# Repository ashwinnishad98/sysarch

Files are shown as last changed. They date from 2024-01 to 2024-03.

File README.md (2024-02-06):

# Non-invasive Sleep Analysis Device

## Description
This device aims to provide a non-invasive way of tracking an individual's sleep quality. It will leverage a force sensor that is placed underneath a mattress to quantify time spent in Rapid Eye Movement (REM) and Non-Rapid Eye Movement (Non-REM) sleep. The user will be able to see their sleep quality once awake, through a stepper-motor controlled gauge needle that indicated sleep quality percentage, which ranges from 0-100%.
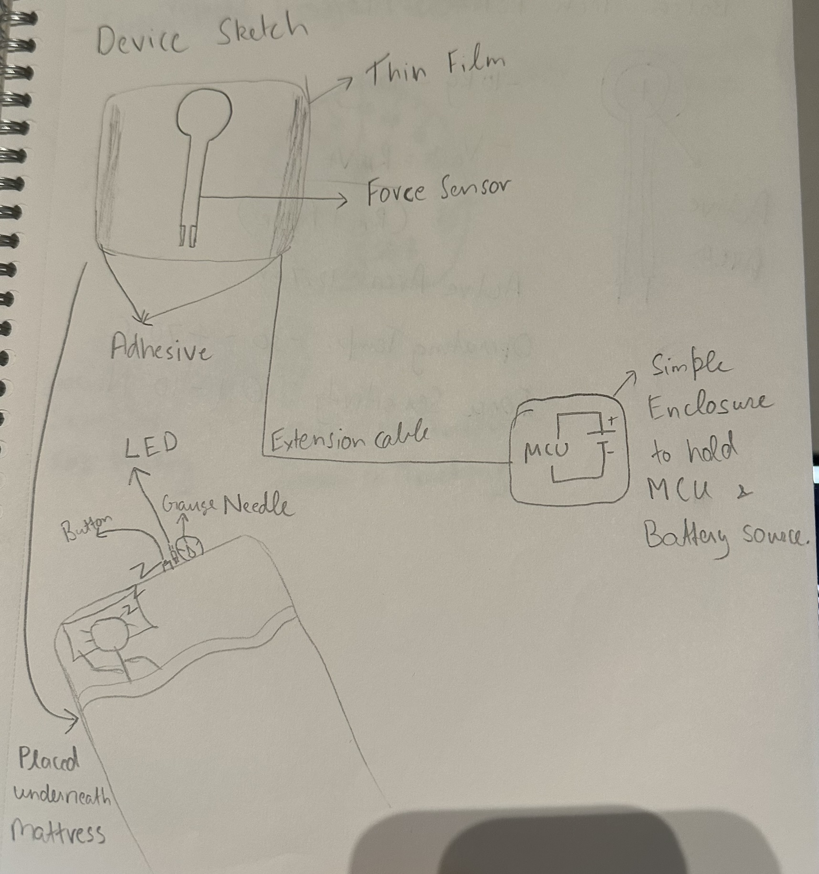
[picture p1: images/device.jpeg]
Device Sketch


## Power Consumption Spreadsheet
[URL](https://docs.google.com/spreadsheets/d/1Ds0gf-FW2-m5mJB0DvBmWuOtr-a-fM6qRe99MvLTX7Y/edit#gid=1000455818)

# Processor
## Seeed Xiao ESP32 S3
This microcontroller has both Wi-Fi and bluetooth capabilties, combined with a small form factor which is ideal for this device. It has 2 pins that can be used for supplying voltage, either 5V or 3.3V.

# Sensor
## Force Sensor: Bolsen Tech FSR402
This is a force sensor, that essentially converts pressure applied against the sensor into changes in resistance. This can be placed underneath the mattress to identify and track body movement over the sleep tracking period. It can be used within a range of 10KG-100KG.
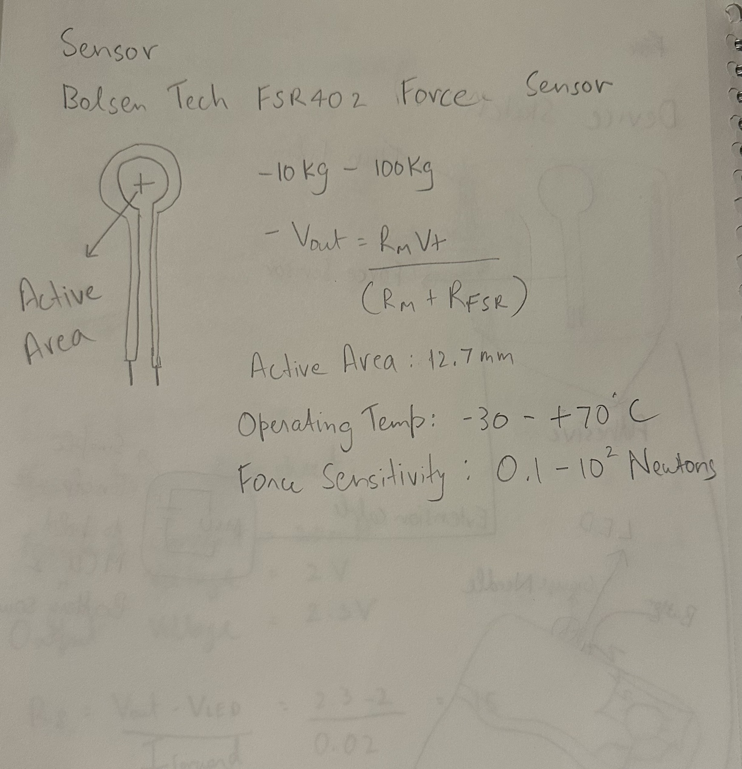
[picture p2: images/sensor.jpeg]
Sensor Sketch


# Displays
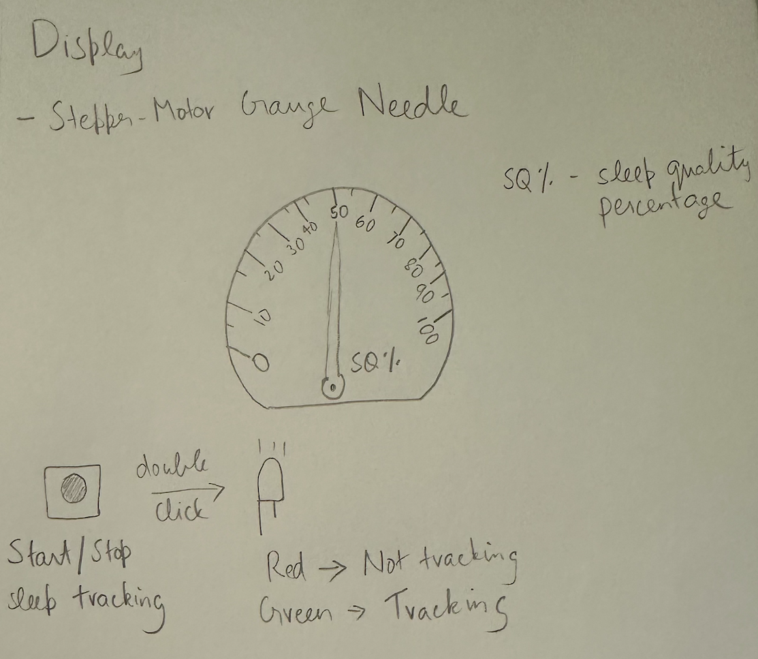
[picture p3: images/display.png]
Display Sketch

## Button
The button will be used by the user to start/stop the sleep tracking. Additionally, it will be programmed to where a double click shows if the device is currently tracking sleep through the LED output.

## LED
The LED will be used to indicate whether the device is currently tracking sleep and will be activated by the button. Upon double clicking the button, red will indicate that the device is not tracking and green will indicate vice-versa.

## Stepper-motor Needle Gauge
The needle gauge will display the measure of sleep quality in percentage. This output is triggered when the user clicks the button to stop the sleep tracking.

## System Architecture Diagram
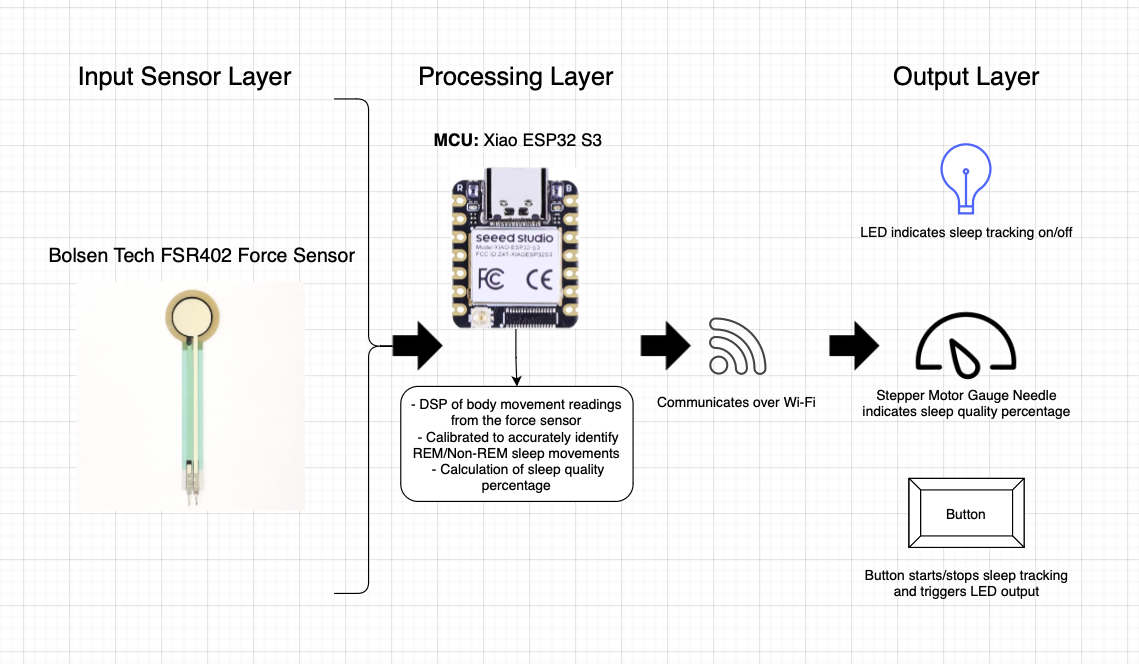
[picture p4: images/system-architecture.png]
System Architecture


## Functionality Diagram
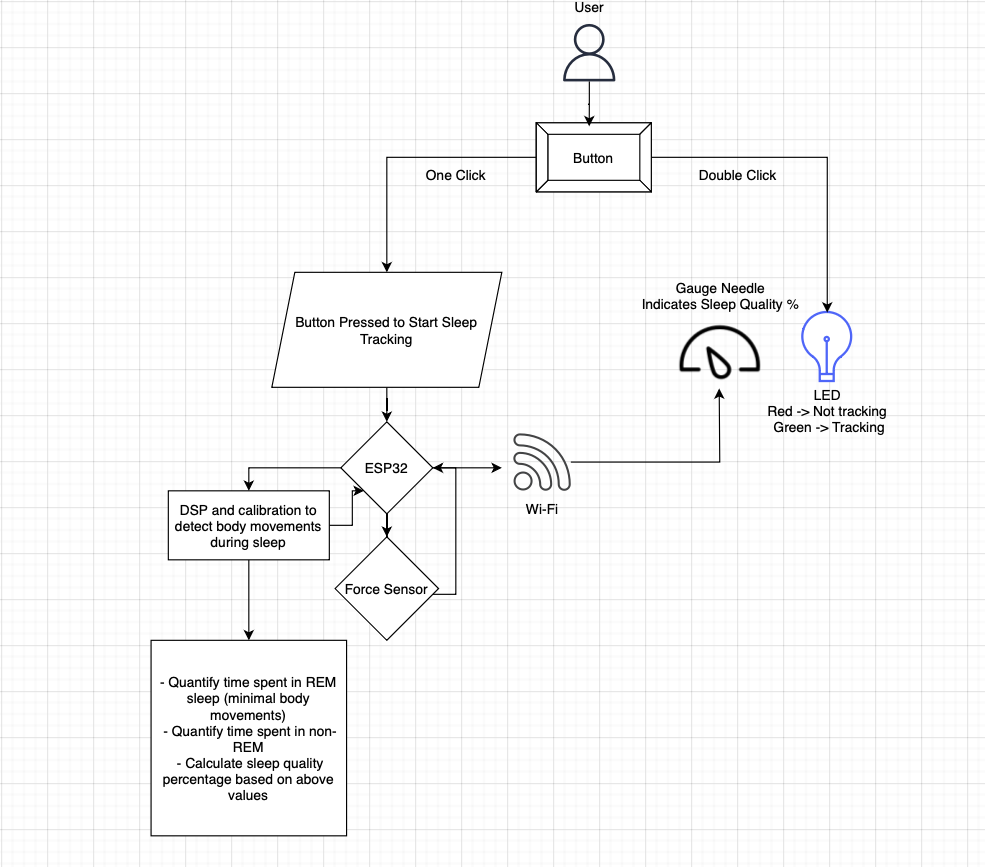
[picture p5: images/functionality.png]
Functionality


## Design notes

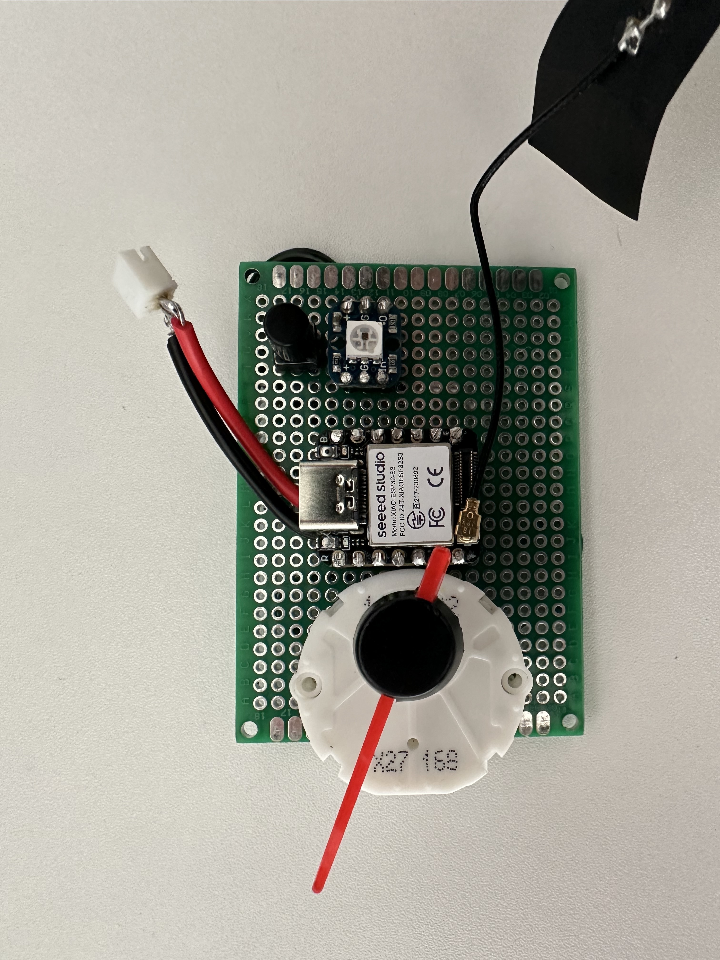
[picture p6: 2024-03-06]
images/displayPerf.jpg

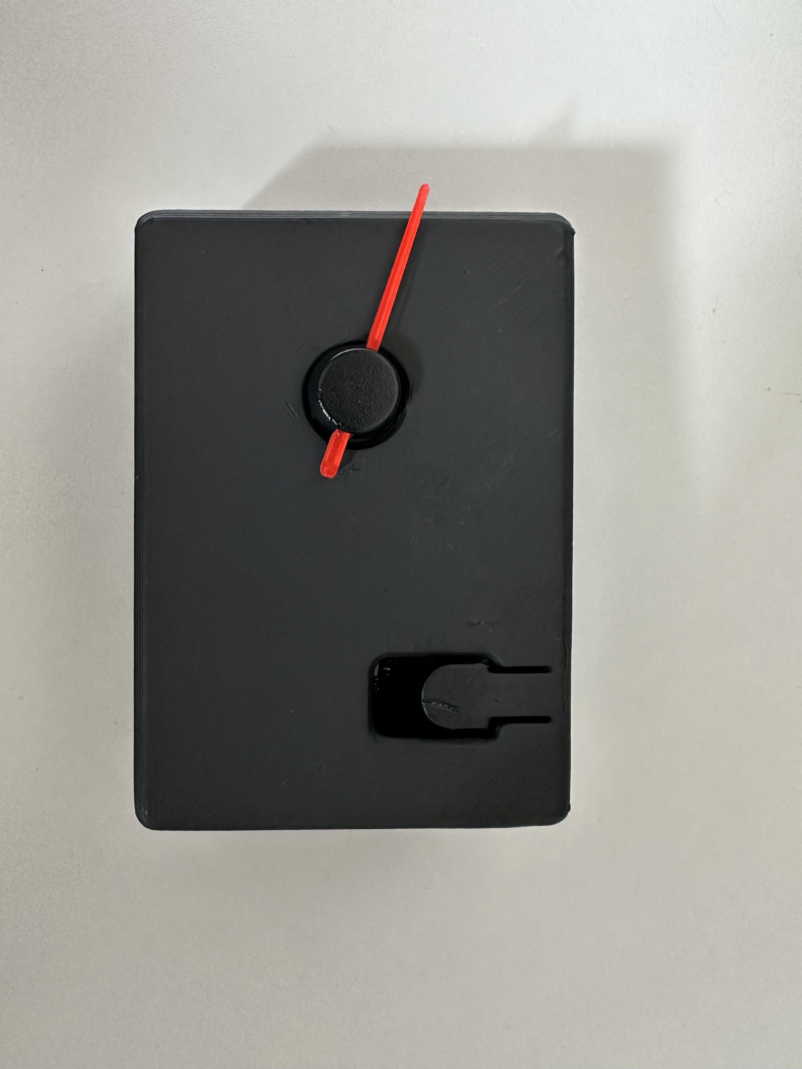
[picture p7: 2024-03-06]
images/display1.jpg

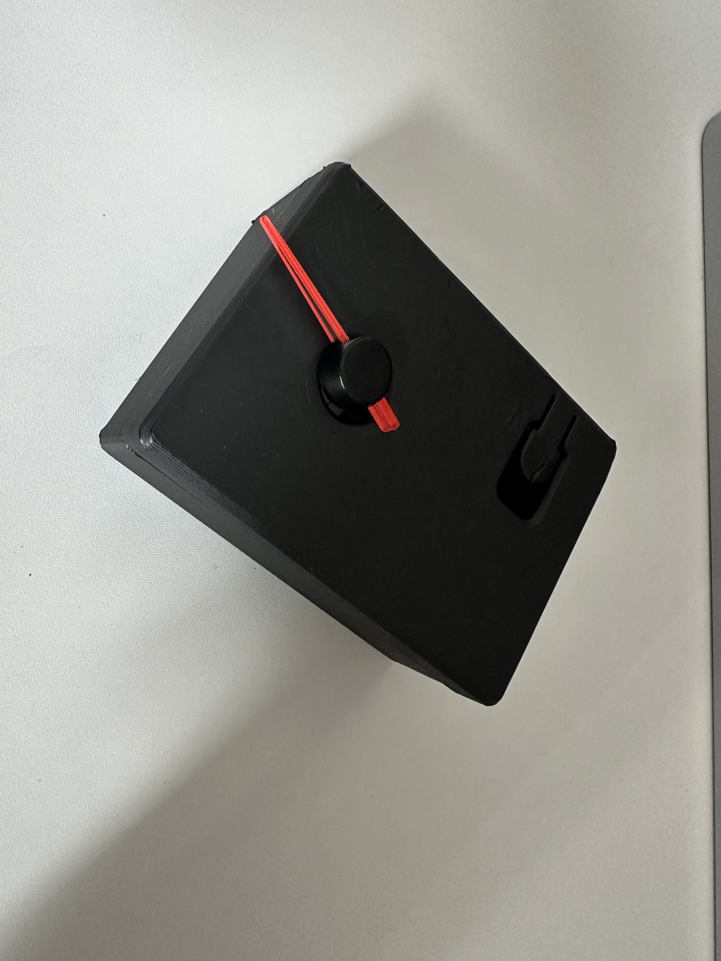
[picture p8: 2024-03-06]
images/display.jpg

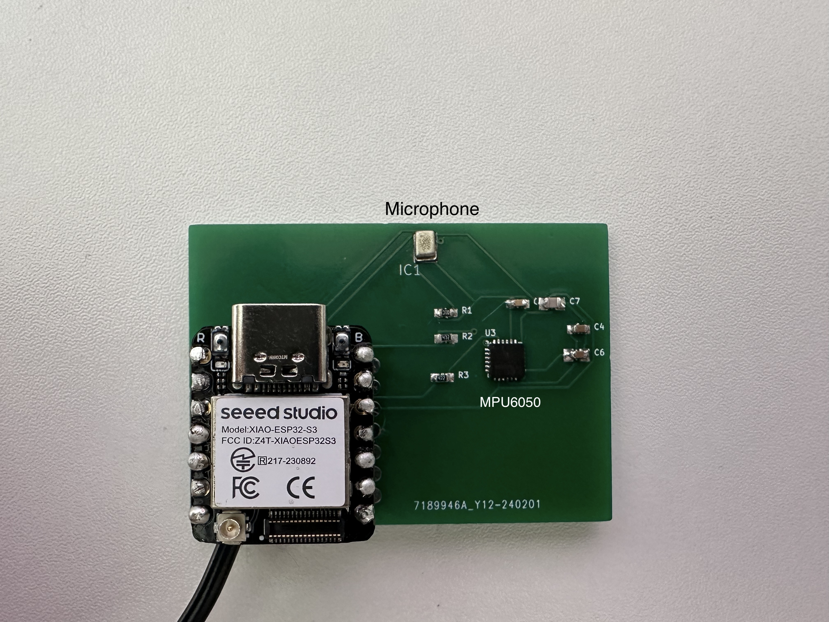
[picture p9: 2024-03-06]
images/pcb.jpg

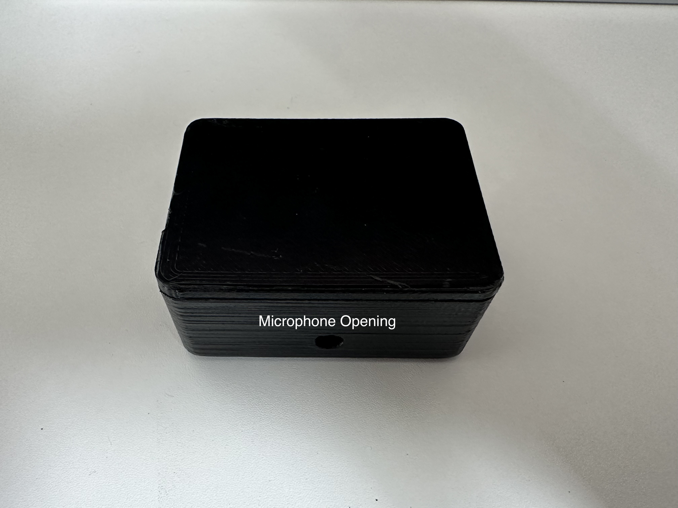
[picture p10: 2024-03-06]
images/sensing.jpg

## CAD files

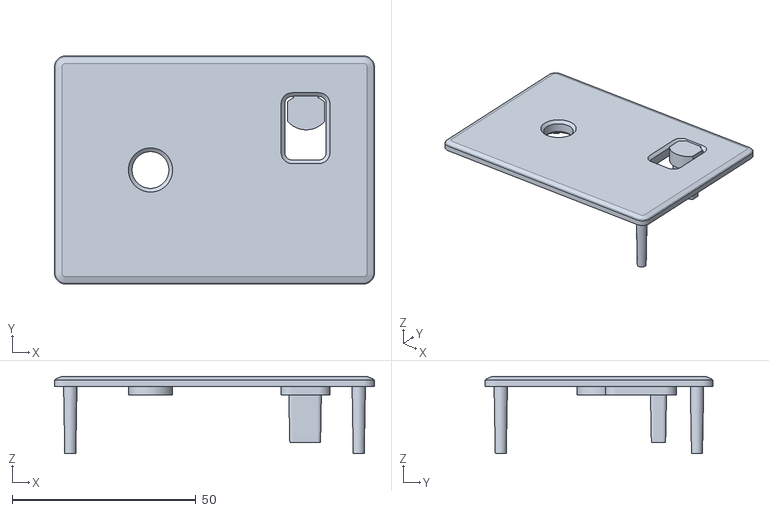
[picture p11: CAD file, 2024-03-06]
CAD/STL/display/lidnew.stl
87.0 x 62.0 x 21.0

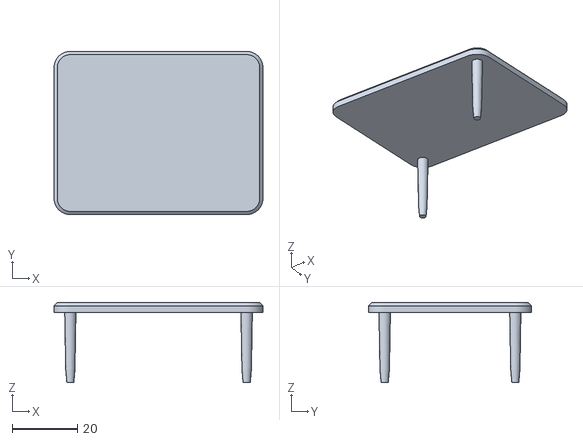
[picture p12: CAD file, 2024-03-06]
CAD/STL/sensing/sensingLid.stl
64.0 x 50.0 x 24.5

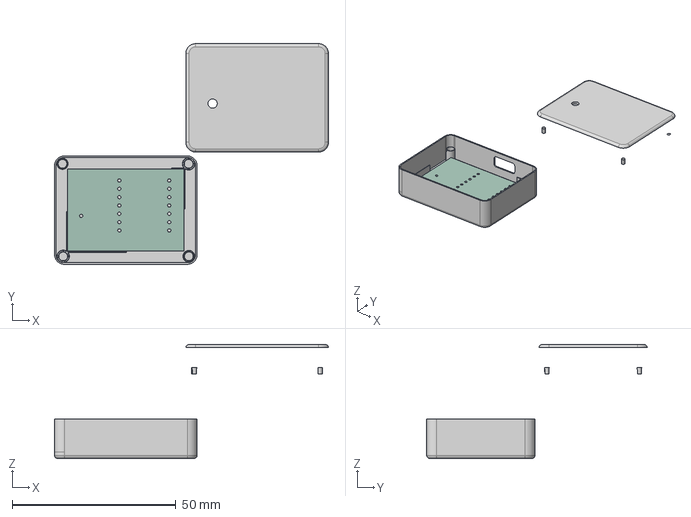
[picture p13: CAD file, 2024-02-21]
CAD/V2SensingEnclosure v21.step
83.6 x 67.3 x 34.8 mm

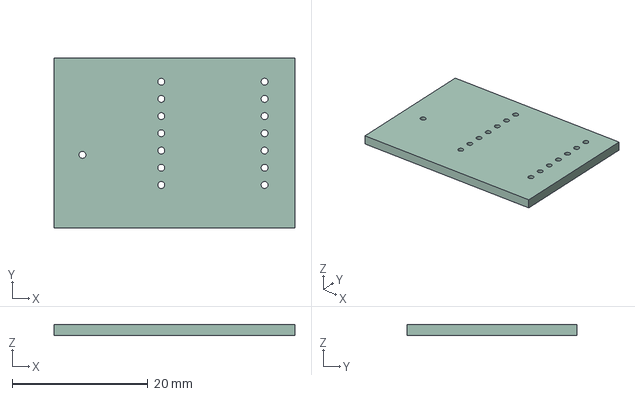
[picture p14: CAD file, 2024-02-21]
kicad/FinalProject/v2sensing.STEP
35.5 x 25.1 x 1.60 mm

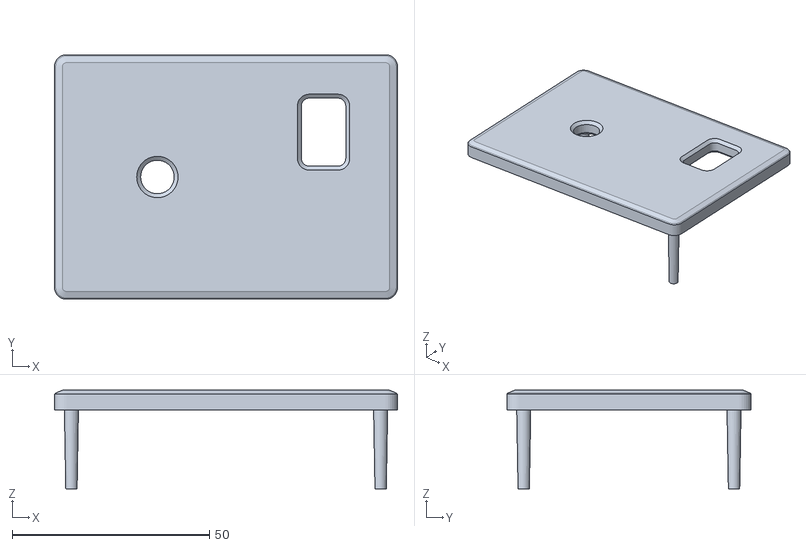
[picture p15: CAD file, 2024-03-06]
CAD/STL/display/displayLidV2.stl
87.0 x 62.0 x 25.0

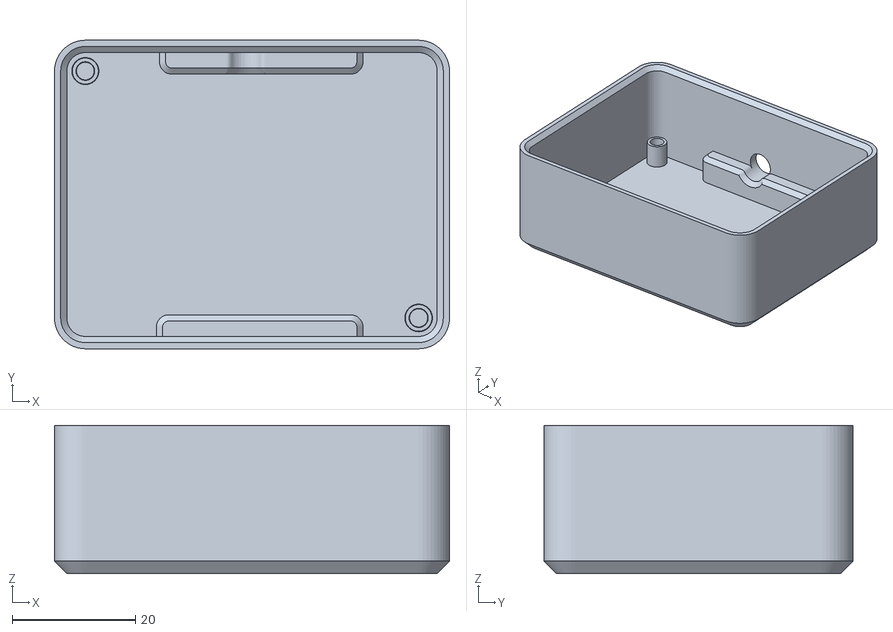
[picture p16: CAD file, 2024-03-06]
CAD/STL/sensing/sensingBase.stl
64.0 x 50.0 x 24.0

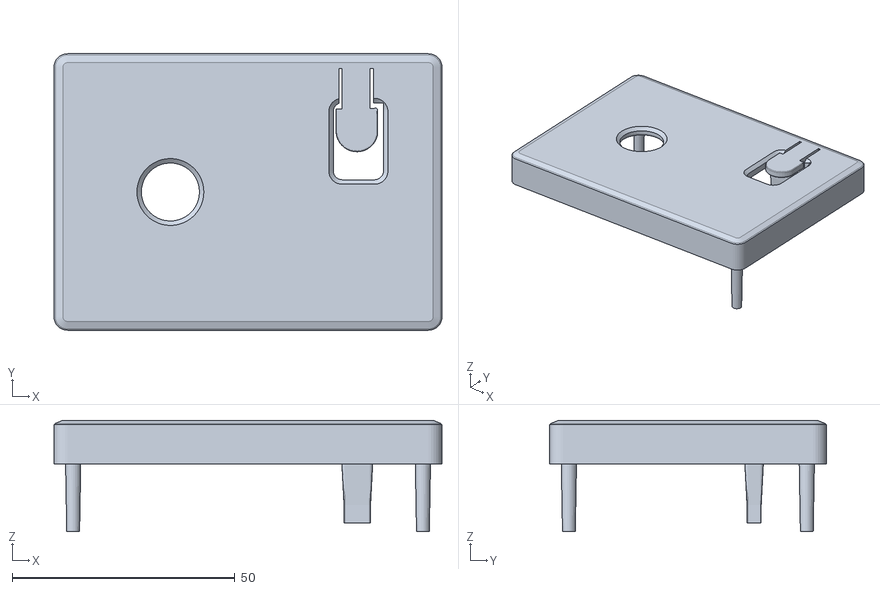
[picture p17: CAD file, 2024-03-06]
CAD/STL/display/newnewlid.stl
87.0 x 62.0 x 25.0

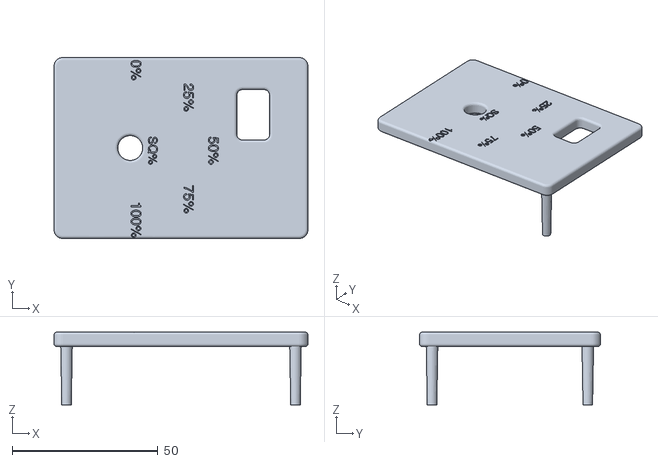
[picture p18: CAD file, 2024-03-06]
CAD/STL/display/lidv1.stl
87.0 x 62.0 x 25.0

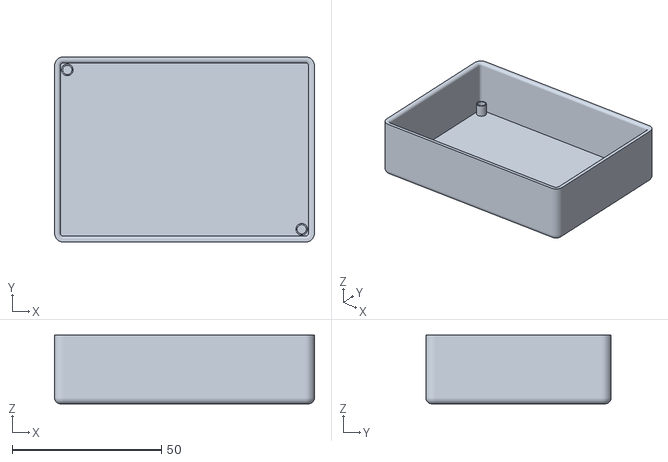
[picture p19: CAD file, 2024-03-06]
CAD/STL/display/basev1.stl
87.0 x 62.0 x 23.0

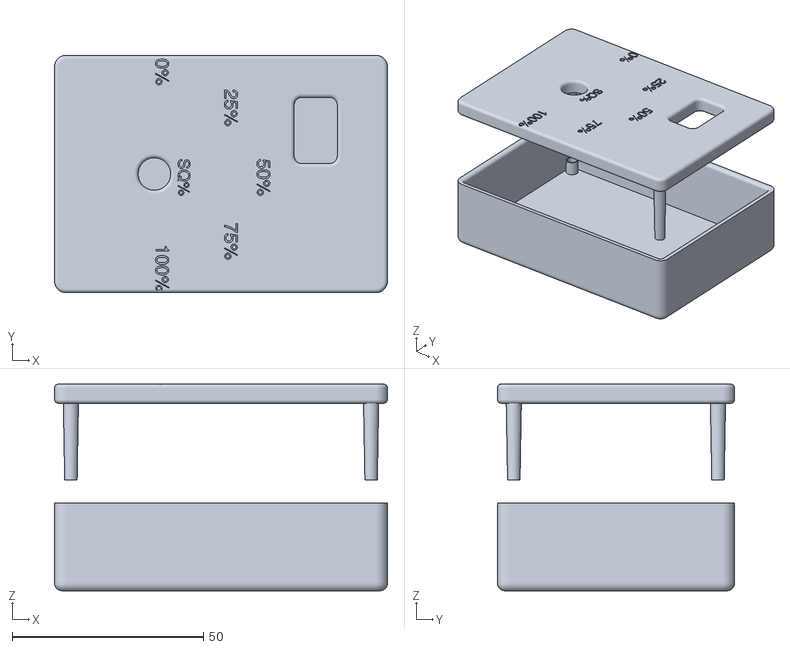
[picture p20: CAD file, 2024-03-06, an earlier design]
CAD/STL/display/displaydeviceperf v24.stl
87.0 x 62.0 x 54.0

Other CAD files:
CAD/STL/display/displaydeviceperf v29.stl
CAD/STL/display/lid_new_ash.stl
CAD/V2SensingEnclosure v21.f3d

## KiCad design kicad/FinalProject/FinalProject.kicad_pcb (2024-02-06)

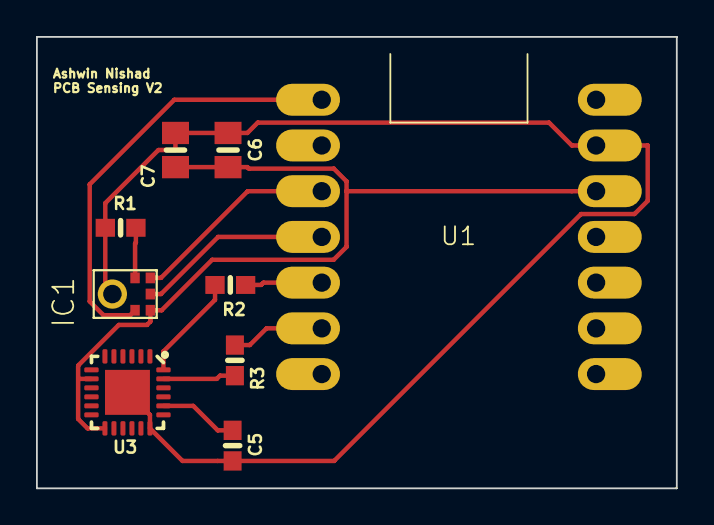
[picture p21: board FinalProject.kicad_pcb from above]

Board: 2 copper layers, 35.5 x 25.1 mm, 9 parts (0 on the bottom side), 11 nets.

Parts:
C5: 2.2nF; 0603-NO
C6: 1uF; 0805-NO
C7: 220pF; 0805-NO
IC1: MIC; SPH0645LM4H
R1: 10k; 0603-NO
R2, R3: 4.7k; 0603-NO
U1: XIAO_ESP32_SENSE
U3: MPU-6050; QFN24_4MM_SMSC

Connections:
/3.3V: C6.1, C7.1, IC1.5 (VDD), U1.10 (3V3), U3.8 (VLOGIC), U3.13 (VDD)
/CPOUT: C5.1, U3.20 (CPOUT)
/SCL_3V: R3.2, U3.23 (SCL)
/SDA_3V: R2.1, U3.24 (SDA)
/SELECT: IC1.2 (SELECT), R1.2
GND: C5.2, C6.2, C7.2, IC1.3 (GND), R1.1, U1.9 (GND), U3.18 (GND), U3.THERM (THERMAL)
unnamed: IC1.4 (BCLK), U1.1 (GPIO1_A0_D0)
unnamed: IC1.6 (DATA), U1.4 (GPIO4_A3_D3)
unnamed: IC1.1 (WS), U1.3 (GPIO3_A2_D2)
unnamed: R2.2, U1.5 (GPIO4_A3_D3_SDA)
unnamed: R3.1, U1.6 (GPIO6_A5_D5_SCL)

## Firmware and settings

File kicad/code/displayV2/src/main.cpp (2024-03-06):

#include <Arduino.h>
#include <Adafruit_NeoPixel.h>
#include <Stepper.h>
#include <BLEDevice.h>
#include <BLEUtils.h>
#include <BLEScan.h>
#include <BLEAdvertisedDevice.h>

// display is 1301

// The remote service we wish to connect to.
static BLEUUID serviceUUID("ea1ac798-29db-461d-9d49-109d7f01f0dd");
// The characteristic of the remote service we are interested in.
static BLEUUID charUUID("cd0ac878-6800-4b50-be03-4eef6a25b14f");

static boolean doConnect = false;
static boolean connected = false;
static boolean doScan = false;
static BLERemoteCharacteristic *pRemoteCharacteristic;
static BLEAdvertisedDevice *myDevice;

#define BUTTON_PIN D0 // button pin
#define PIXEL_PIN D7  // NeoPixel pin
#define PIXEL_COUNT 1
#define STEPS 315
bool buttonEnabled = false;

int motorPins[4] = {D5, D6, D3, D1};

int inputSignal = 0;
int currentPosition = 0;

Adafruit_NeoPixel strip(PIXEL_COUNT, PIXEL_PIN, NEO_GRB + NEO_KHZ800);
Stepper myStepper(STEPS, motorPins[0], motorPins[1], motorPins[2], motorPins[3]);

unsigned long lastButtonPress = 0;
bool onState = false; // True means ON state, False means OFF state.

/**
 * Sets the color of the NeoPixel.
 *
 * @param red The intensity of the red color (0-255).
 * @param green The intensity of the green color (0-255).
 * @param blue The intensity of the blue color (0-255).
 * @param duration The duration in milliseconds for which the color should be displayed.
 */
void setNeoPixelColor(uint8_t red, uint8_t green, uint8_t blue, int duration)
{
  strip.setPixelColor(0, strip.Color(red, green, blue));
  strip.show();
  delay(duration);
  strip.setPixelColor(0, strip.Color(0, 0, 0));
  strip.show();
}

void toggleColorBasedOnState()
{
  if (onState)
  {
    // If ON state, double click turns the LED green
    setNeoPixelColor(0, 255, 0, 3000); // Green for 5 seconds
  }
  else
  {
    // If OFF state, double click turns the LED red
    setNeoPixelColor(255, 0, 0, 3000); // Red for 5 seconds
  }
}

void sendCommand(const char *command)
{
  if (connected)
  {
    // Assuming 'pRemoteCharacteristic' is correctly set up to point to the server's characteristic
    pRemoteCharacteristic->writeValue(command, strlen(command));
    Serial.println("Command sent: " + String(command));
  }
}

class MyClientCallback : public BLEClientCallbacks
{
  void onConnect(BLEClient *pclient)
  {
  }

  void onDisconnect(BLEClient *pclient)
  {
    connected = false;
    Serial.println("onDisconnect");
  }
};

void moveStepper(int value)
{
  // Invert the mapping so that 0% maps to the left side (0 degrees) and 100% to the right side (315 degrees).
  // This means we subtract the calculated target position from the maximum to invert the direction.
  float targetPositionDegrees = 315 - (315.0 / 100) * value;

  // Calculate the target position in steps.
  // Since 600 steps are equivalent to 315 degrees, we find the proportional number of steps for the target position.
  int targetPositionSteps = (int)((600 / 315.0) * targetPositionDegrees);

  // Calculate the number of steps to move from the current position.
  int stepsToTarget = targetPositionSteps - currentPosition;

  // Move the stepper motor by the calculated steps.
  myStepper.step(stepsToTarget);

  // Update the current position in steps.
  currentPosition = targetPositionSteps;
}

void notifyCallback(BLERemoteCharacteristic *pBLERemoteCharacteristic, uint8_t *pData, size_t length, bool isNotify)
{
  String value = "";
  for (int i = 0; i < length; i++)
  {
    value += (char)pData[i];
  }
  Serial.print("Received data: ");
  Serial.println(value);

  // Assuming value is directly the parameter for moveStepper
  int sleepQuality = value.toInt();
  moveStepper(sleepQuality);
}

bool connectToServer()
{
  Serial.print("Forming a connection to ");
  Serial.println(myDevice->getAddress().toString().c_str());

  BLEClient *pClient = BLEDevice::createClient();
  Serial.println(" - Created client");

  pClient->setClientCallbacks(new MyClientCallback());

  // Connect to the remove BLE Server.
  pClient->connect(myDevice); // if you pass BLEAdvertisedDevice instead of address, it will be recognized type of peer device address (public or private)
  Serial.println(" - Connected to server");
  pClient->setMTU(517); // set client to request maximum MTU from server (default is 23 otherwise)

  // Obtain a reference to the service we are after in the remote BLE server.
  BLERemoteService *pRemoteService = pClient->getService(serviceUUID);
  if (pRemoteService == nullptr)
  {
    Serial.print("Failed to find our service UUID: ");
    Serial.println(serviceUUID.toString().c_str());
    pClient->disconnect();
    return false;
  }
  Serial.println(" - Found our service");

  // Obtain a reference to the characteristic in the service of the remote BLE server.
  pRemoteCharacteristic = pRemoteService->getCharacteristic(charUUID);
  if (pRemoteCharacteristic == nullptr)
  {
    Serial.print("Failed to find our characteristic UUID: ");
    Serial.println(charUUID.toString().c_str());
    pClient->disconnect();
    return false;
  }
  Serial.println(" - Found our characteristic");

  // Read the value of the characteristic.
  if (pRemoteCharacteristic->canRead())
  {
    std::string value = pRemoteCharacteristic->readValue();
    Serial.print("The characteristic value was: ");
    Serial.println(value.c_str());
  }

  if (pRemoteCharacteristic->canNotify())
    pRemoteCharacteristic->registerForNotify(notifyCallback);

  connected = true;
  return true;
}

/**
 * Scan for BLE servers and find the first one that advertises the service we are looking for.
 */
class MyAdvertisedDeviceCallbacks : public BLEAdvertisedDeviceCallbacks
{
  /**
   * Called for each advertising BLE server.
   */
  void onResult(BLEAdvertisedDevice advertisedDevice)
  {

    // We have found a device, let us now see if it contains the service we are looking for.
    if (advertisedDevice.haveServiceUUID() && advertisedDevice.isAdvertisingService(serviceUUID))
    {

      BLEDevice::getScan()->stop();
      myDevice = new BLEAdvertisedDevice(advertisedDevice);
      doConnect = true;
      doScan = true;

    }
  }
};

void setup()
{
  Serial.begin(9600);
  BLEDevice::init("DISPLAY_CLIENT");

  pinMode(BUTTON_PIN, INPUT_PULLUP);
  strip.begin();
  strip.show(); // Initialize all pixels to 'off'

  BLEScan *pBLEScan = BLEDevice::getScan();
  pBLEScan->setAdvertisedDeviceCallbacks(new MyAdvertisedDeviceCallbacks());
  pBLEScan->setInterval(1349);
  pBLEScan->setWindow(449);
  pBLEScan->setActiveScan(true);
  pBLEScan->start(5, false);

  myStepper.setSpeed(100);
}

void loop()
{
  static uint8_t lastButtonState = HIGH;
  static unsigned long lastDebounceTime = 0;
  const unsigned long debounceDelay = 50;
  uint8_t reading = digitalRead(BUTTON_PIN);
  static bool commandSent = false;
  static bool isFirstClick = false;

  if (doConnect == true)
  {
    if (connectToServer())
    {
      Serial.println("We are now connected to the BLE Server.");
    }
    else
    {
      Serial.println("We have failed to connect to the server; there is nothin more we will do.");
    }
    doConnect = false;
  }

  if (reading != lastButtonState)
  {
    lastDebounceTime = millis();
  }

  // Button state has changed
  if (reading == LOW && lastButtonState == HIGH)
  {
    if (!buttonEnabled)
    {
      Serial.println("Button enabled");
      buttonEnabled = true;
      setNeoPixelColor(255, 255, 255, 1000);
      sendCommand("start");
      commandSent = true;
    }
    else
    {

      if ((millis() - lastDebounceTime) > debounceDelay)
      {
        // Button state has changed
        if (reading == LOW && lastButtonState == HIGH)
        {
          if (!buttonEnabled)
          {
            Serial.println("Button enabled");
            buttonEnabled = true;                  // Activate button functionality on first press
            setNeoPixelColor(255, 255, 255, 2000); // Indicate button activation
            sendCommand("start");
            commandSent = true;
          }
          else
          {
            // Single click logic (not a double click) - toggle start/stop
            isFirstClick = false; // Reset for the next action
            if (commandSent)
            {
              buttonEnabled = false;  
              sendCommand("stop");
              commandSent = false; // Reset commandSent for toggling
            }
            else
            {
              sendCommand("start");
              commandSent = true;
            }
          }

          // For subsequent presses, check for double click for LED color toggle
          static unsigned long firstClickTime = 0;
          if (isFirstClick && (millis() - firstClickTime) < 500)
          {
            // Double click detected
            toggleColorBasedOnState();
            isFirstClick = false;
          }
          else if (!isFirstClick)
          {
            isFirstClick = true;
            firstClickTime = millis();
          }
          else
          {
            // Single click logic (not a double click) - toggle start/stop
            isFirstClick = false; // Reset for the next action
            if (commandSent)
            {
              sendCommand("stop");
              commandSent = false; // Reset commandSent for toggling
            }
            else
            {
              sendCommand("start");
              commandSent = true;
            }
          }
        }
      }

      lastButtonState = reading;
    }
    delay(1000);
  }
}

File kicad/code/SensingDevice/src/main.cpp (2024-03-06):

#include <Wire.h>
#include <Adafruit_MPU6050.h>
#include <Adafruit_Sensor.h>
#include "driver/i2s.h"
#include <BLEDevice.h>
#include <BLEServer.h>
#include <BLEUtils.h>
#include <BLE2902.h>
#include <sleepanalysis.h>
#define SERVICE_UUID "ea1ac798-29db-461d-9d49-109d7f01f0dd"
#define CHARACTERISTIC_UUID "cd0ac878-6800-4b50-be03-4eef6a25b14f"
BLEServer *pServer = NULL;
BLECharacteristic *pCharacteristic = NULL;
bool deviceConnected = false;
bool oldDeviceConnected = false;

// I2S pins
#define I2S_WS 3
#define I2S_SCK 1
#define I2S_SD 4
#define SAMPLE_RATE 16000
#define BITS_PER_SAMPLE 16
#define CHANNELS 1
#define RECORD_TIME 60000 // 60 seconds in milliseconds

Adafruit_MPU6050 mpu;

bool lastButton = false;

// High pass filter parameters
float alpha = 0.9;
float prevFilteredX = 0, prevFilteredY = 0, prevFilteredZ = 0;
float prevRawX = 0, prevRawY = 0, prevRawZ = 0;

unsigned long startMillis;
const unsigned long period = 60000;      // 1 minute
const unsigned long awakePeriod = 15000; // 15 seconds
unsigned long awakeStartMillis;
unsigned int awakeCounter = 0;
bool isAwake = false;
bool startCollection = false;

class MyServerCallbacks : public BLEServerCallbacks
{
  void onConnect(BLEServer *pServer)
  {
    deviceConnected = true;
    startCollection = false;
  };

  void onDisconnect(BLEServer *pServer)
  {
    deviceConnected = false;
  }
};

class MyCharacteristicCallbacks : public BLECharacteristicCallbacks
{
  void onWrite(BLECharacteristic *pCharacteristic) override
  {
    std::string value = pCharacteristic->getValue();
    if (value == "start")
    {
      startCollection = true;
      Serial.println("Start command received");
    }
    else if (value == "stop")
    {
      startCollection = false;
      Serial.println("Stop command received");
    }
  }
};

int collectMPUData()
{
  // Read the raw values
  sensors_event_t a, g, temp;
  mpu.getEvent(&a, &g, &temp);

  // High pass filter to remove the influence of gravity
  float filteredX = alpha * (prevFilteredX + a.acceleration.x - prevRawX);
  float filteredY = alpha * (prevFilteredY + a.acceleration.y - prevRawY);
  float filteredZ = alpha * (prevFilteredZ + a.acceleration.z - prevRawZ);

  // Update the previous values for the next iteration
  prevFilteredX = filteredX;
  prevFilteredY = filteredY;
  prevFilteredZ = filteredZ;
  prevRawX = a.acceleration.x;
  prevRawY = a.acceleration.y;
  prevRawZ = a.acceleration.z;

  // Calculate the magnitude of the acceleration vector
  float magnitude = sqrt(filteredX * filteredX + filteredY * filteredY + filteredZ * filteredZ);

  // Threshold to determine movement, tune based on your requirements
  float threshold = 0.5; // Example threshold, adjust as needed

  // Detect movement based on the magnitude surpassing the threshold
  if (magnitude > threshold)
  {
    if (!isAwake)
    {
      isAwake = true;
      awakeStartMillis = millis();
    }
  }
  else
  {
    isAwake = false;
  }

  // If there was movement for 15 continuous seconds, increment the counter
  if (isAwake && (millis() - awakeStartMillis >= awakePeriod))
  {
    awakeCounter++;
    isAwake = false; // Reset the awake status
    Serial.println("Movement detected, person is awake.");
  }
  int sleepQuality;
  // Every minute, report the number of times movement was detected
  if (millis() - startMillis >= period)
  {

    switch (awakeCounter)
    {
    case 0:
      sleepQuality = 100;
      break;
    case 1:
      sleepQuality = 75;
      break;
    case 2:
      sleepQuality = 50;
      break;
    case 3:
      sleepQuality = 25;
      break;
    case 4:
      sleepQuality = 0;
      break;
    default:
      sleepQuality = 0; // Handles the case if it's more than 4 for some reason
    }

    Serial.print("One minute passed. Awake count: ");
    Serial.print(awakeCounter);
    Serial.print(", Sleep Quality: ");
    Serial.println(sleepQuality);

    // Reset counter and timer
    awakeCounter = 0;
    startMillis = millis();
  }
  Serial.println("Sleep quality: " + String(sleepQuality));
  return sleepQuality;
}

void collectMicData()
{
  // Buffer to store the received data
  const int buffer_size = SAMPLE_RATE * BITS_PER_SAMPLE / 8 * CHANNELS * 60; // 60 seconds buffer
  char *audio_data = new char[buffer_size];
  size_t bytes_read = 0;

  unsigned long startMillis = millis();
  while (millis() - startMillis < RECORD_TIME)
  {
    // Read data from I2S bus
    i2s_read(I2S_NUM_0, (void *)audio_data, buffer_size, &bytes_read, portMAX_DELAY);
  }

  // At this point, audio_data contains 1 minute of audio, which can be processed or saved.
  delete[] audio_data;

  // Create a signal object for the model
  signal_t signal;
  signal.total_length = sizeof(audio_data) / sizeof(audio_data[0]);
  signal.get_data = &get_audio_signal_data;

  // Perform inference
  ei_impulse_result_t result;
  EI_IMPULSE_ERROR res = run_classifier(&signal, &result, true);

  if (res == EI_IMPULSE_OK)
  {
    // Print the classification result
    Serial.print("Label: ");
    Serial.println(result.classification.label);
    Serial.print("Confidence: ");
    Serial.println(result.classification.value);
  }
  else
  {
    Serial.println("Inference failed");
  }
}
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

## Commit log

2024-01-18 added initial v1 kicad schematic
    [schematic_v1.kicad_sch]
2024-01-25 kicad/finalproject/ contains the kicad files for schematic and pcb
    [Adafruit I2S Mic SPK0415HM4H.sch, Adafruit MPU6050.sch, FinalProject.kicad_pcb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]
2024-02-06 added datasheets for led and stepper motor
    [FinalProject-B_Cu.gbr, FinalProject-B_Mask.gbr, FinalProject-B_Paste.gbr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]
2024-02-21 code for display device
    [FinalProject-B_Cu.gbr, FinalProject-B_Mask.gbr, FinalProject-B_Paste.gbr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]
2024-03-06 code for display and sensing
    [FinalProject-B_Cu.gbr, FinalProject-B_Mask.gbr, FinalProject-B_Paste.gbr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]
